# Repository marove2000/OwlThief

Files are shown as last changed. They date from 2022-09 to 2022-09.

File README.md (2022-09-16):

# Owl Thief

A simple joule thief circuit on the back of an owl. If you solder everything right, you can empty old batteries and make the eyes glow orange.

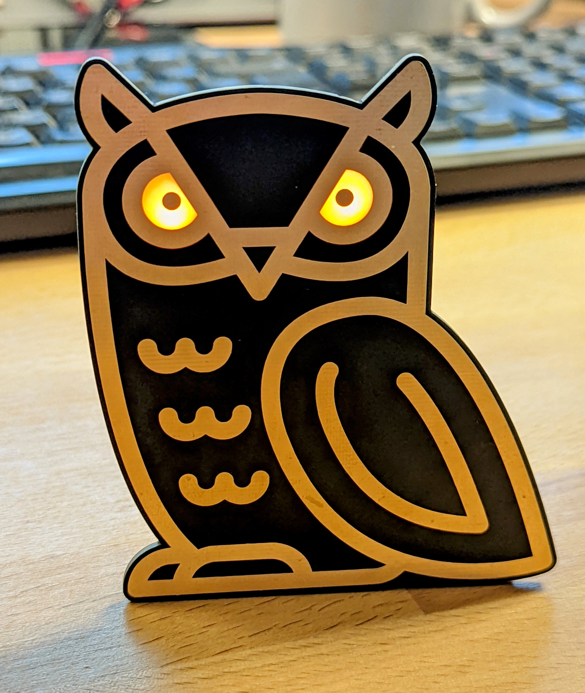
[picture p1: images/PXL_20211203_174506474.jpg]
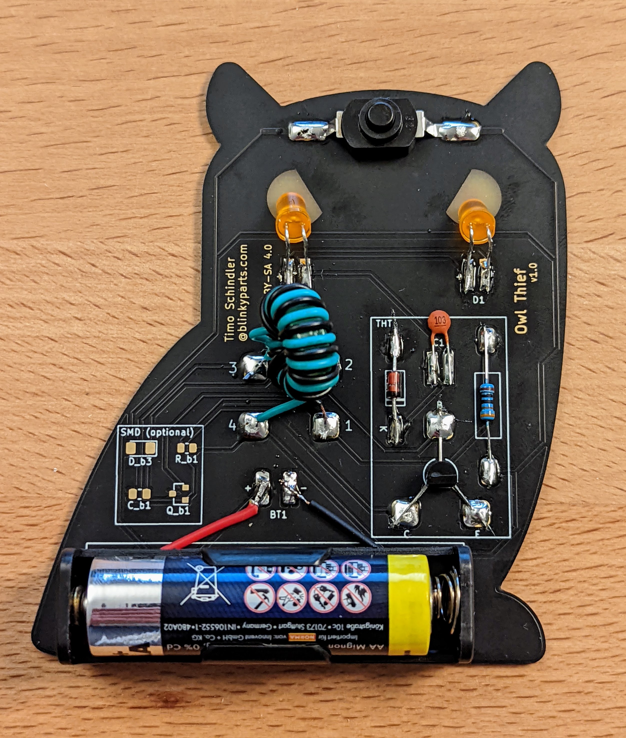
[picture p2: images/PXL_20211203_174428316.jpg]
 

- Status: **Complete**
- Difficulty: **2/5**

### Parts List

| Quantity | Name  | Description | Signing/Colorcode |
|---|---|---|---|
| 1 | C1 | 10nF capacitor | 103 |
| 1 | C_b1  | 10nF SMD capacitor (optional)  | |
| 1 | R1 | 330R resistor | orange,orange,black,black,brown |
| 1 | R_b1  | 330R SMD resistor (optional) | |
| 1 | Q1 | NPN transistor | BC547 |
| 1 | Q_b1  | NPN SMD transistor (optional)  | |
| 1 | D3 | z-diode | |
| 1 | D_b3  | SMD z-diode | |
| 2 | D1,D2 | 5mm orange LED | |
| 1 | SW1 | switch | |
| 1 | B1 | 1x AA battery holder | |
| 1 | | 1 AA battery* | |
| 1 | T1 | coil | |
| 2 | | cable 300mm (needed for coil)  | |
| 1 | | ferrite core (needed for coil) | |

* The batteries are not included in our kits.
The SMD components are not needed. The PCB is made to work with both. Do not mix SMD and THT at the same time.

### Manual
You can find the manual and pictures of every step here: https://github.com/Binary-Kitchen/SolderingTutorial

### Copyright and Authorship

- Board: [CC-BY-SA 4.0](https://creativecommons.org/licenses/by-sa/4.0/) - Timo Schindler @ [blinkyparts.com](https://shop.binkyparts.com)
- Owl SVG [CC-BY-SA](https://creativecommons.org/licenses/by-sa/4.0/) - [Owl by iconixar from NounProject.com](https://thenounproject.com/icon/owl-4070296/) (We've bought a licence, you should honor the artist work too!)

### Buy Kits

You can also buy a ready to make soldering-kit @ [shop.blinkyparts.com](https://shop.blinkyparts.com/de/Der-OwlThief-Eine-goldene-Eule-mit-leuchtenden-Orangen-Augen-Joul-Thief-Schaltung-in-THT-Version/blink234042).

### Press

Wow! We were mentioned in the great heiseonline IT-news magazine: https://www.heise.de/news/Extravagantes-Platinendesign-Mach-s-ein-bisschen-huebscher-7243649.html

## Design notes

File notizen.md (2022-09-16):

Auswahl: https://thenounproject.com/term/owl/4070296/

Owl by iconixar from the Noun Project

https://de.wikipedia.org/wiki/Joule_thief

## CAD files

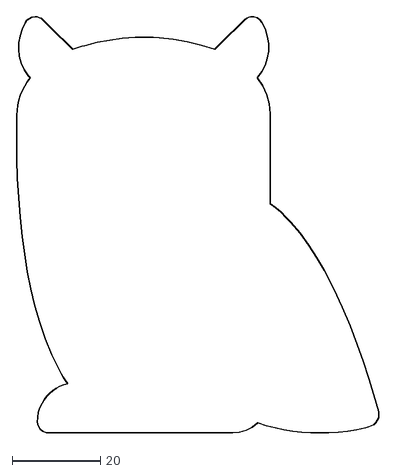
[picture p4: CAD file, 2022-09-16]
outline/outline_only.dxf
82.3 x 94.6

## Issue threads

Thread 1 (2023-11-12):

SMD transistor symbol/connection

muellni, 2023-11-12:
Thanks for this awesome assembly kit. During creation of my SMD-only fork I noticed that the symbol of the SMD transistor `Q_b1` is `Device:Q_NPN_CBE` which in connection with the footprint `Package_TO_SOT_SMD:SOT-23` will lead to a wrong connected transistor.  At least for the transistors I found, like BC 847. The all seem to have the following pinout:
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

I suggest you change the symbol to `Device:Q_NPN_BEC`  which should have the correct pin order.

Closed 2024-03-12.

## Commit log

2022-09-16 added outline files
    [outline_only.dxf]
2022-09-16 added kicad files
    [owlThief-B_Cu.gbr, owlThief-B_Mask.gbr, owlThief-B_SilkS.gbr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]
2023-04-19 added kicad specific gitignore
2023-04-19 addes zipped gerber files for version 1.0
2023-04-19 generated new gerber files
    [owlThief-B_Cu.gbr, owlThief-B_Mask.gbr, owlThief-B_Silkscreen.gbr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]
2023-04-19 deleted old files
    [owlThief.sch]
2023-04-19 modified pcb and added new zones
    [owlThief.kicad_pcb, owlThief.kicad_sch]
2024-03-12 added 1.2 with new coil footprint and some minor fixes
    [owlThief-B_Cu.gbr, owlThief-B_Mask.gbr, owlThief-B_SilkS.gbr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]
2025-01-06 Fix wrong connection of optional SMD transistor Q_b1
    [owlThief.kicad_pcb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]
